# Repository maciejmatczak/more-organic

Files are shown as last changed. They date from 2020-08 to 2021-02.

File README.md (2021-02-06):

# More organic

Last time (five-by-six) Freecad was used to achieve the parametric design of plate and rest of case parts.

Now, the whole design is more complicated. When keys were purely orthogonal, Freecad handled that easily with multi transform, but column stagger + thumb cluster is a bit more challenging.

OpenSCAD with SolidPython was choosen to support CAD design.

There is a couple of interdigitated parts in this project. Initially, the idea was to define everything in `make` dependencies, but that didn't work out. For example: case depends on switches placement (which are placed with script), but also manually placed elements on a PCB itself (uC, jack, etc). But PCB depends on a case itself, as PCB edge definition comes from it...

Whole workflow ended up as a subset of action from `Makefile`, saved intermediate design files within the repo itself (.scad, .dxf, .json data dumps).

This board might be really similar to quite a few already existing great boards out there. An additional knob would be also nice.

# Parts of this project

## Design

The design of shared data, like:

- keys and diode positions
- mounting holes (pcb to plate, plate standoffs)

... is generated from `design/design.py` file. A bit of a math, logic and magic numbers (hand measurments, etc).

## Case

With use of SolidPython and dump of the footrpints from PCB, the whole assembly of plate, cover and pcb design is generated:

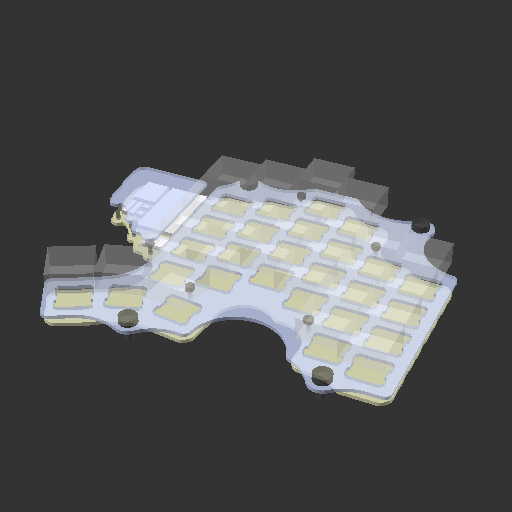
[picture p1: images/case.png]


Additionally, a collisions are shown in red (need of a manual validation):

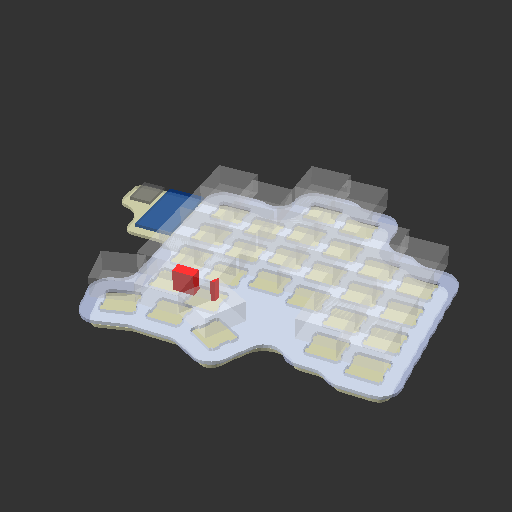
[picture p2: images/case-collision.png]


The whole idea for this design is to be kind of _organic_. Edges are naturally created form particular elements being _melted_ with each other. I am proud of that one.

Some footprints from KiCAD were "redesigned" in OpenSCAD as well (basic shapes).

Different coordinate system between this 2 worlds (KiCAD and OpenSCAD) is not fun. Also, KiCAD and it's weird `(0, 0)` placement.

Also, this board doesn't have a bottom plate.

From python scripts .scad files are baked, then .dxf and images. .dxf are used as a PCBs edge lines (for main PCB, cover and plate).

## PCB

Ordinary PCB design. Needs manual routing followup after every `make pcb-place` is invoked, manual PCB edge reload from case's .dxf.

There is a small chaos in submodules and parts actually being used. The really used one, should be:

- [Keebio-Parts.pretty](github.com:keebio/Keebio-Parts.pretty)
- [keebio-components](github.com:keebio/keebio-components)
- [keyswitches.pretty](github.com/maciejmatczak/keyswitches.pretty), forked from [daprice's](github.com/daprice/keyswitches.pretty); I additionally modify one footprint to be reversible

# Afterthoughts

Scripting backup is great. But a really well thought and defined data flow needs be designed first to keep everything well working with each other in a more complicated design like this.

Clean stages of project are a key, I believe. Imagine if your work had to be done by different engineers. Mechanical design, electrical design. Which parts of a project are a common data that needs to be agreed and locked? And how to validate if you didn't mess up with some updates?

In a middle of a design, there would be a need to change something - for sure! The changes in the _root_ should naturally produce a dependant actions to follow up (that's should be clearly visible). Steps should be clear.

Status quo is not exactly how I was imaging it, but with recent RSI issues being more severe, this project took longer than I thought. And one failed fabrication ;).

Highlights:

- KiCAD design scripting
  - data dumpers from a KiCAD PCB
  - footprint placers from such dump - with filtering included
- OpenSCAD and SolidPython
  - idea for a companion libraries (to KiCAD's)
- General project validation - pytest suite
  - checking characteristic elements in designs (number of holes)
  - proper file age (drc report should be **younger** than a design itself)

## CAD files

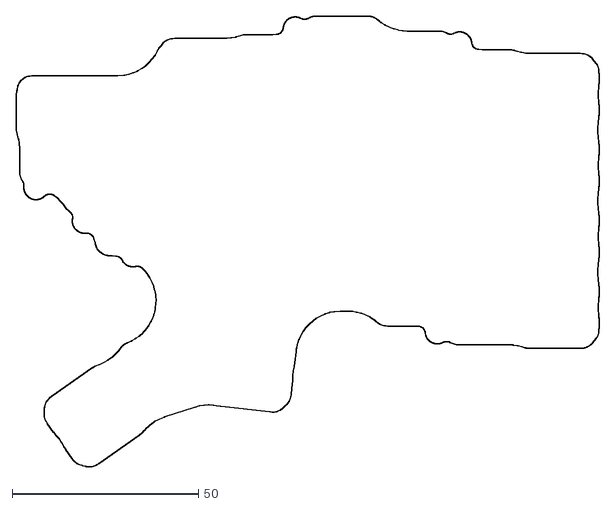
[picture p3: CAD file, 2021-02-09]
data/case/pcb.dxf
156.4 x 120.9

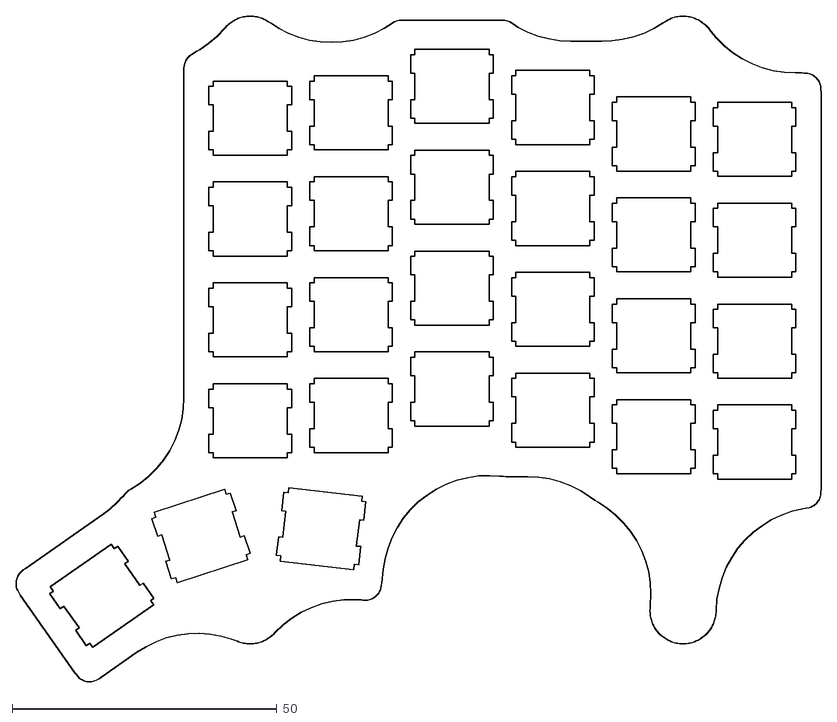
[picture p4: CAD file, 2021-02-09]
data/case/plate.dxf
152.0 x 125.7

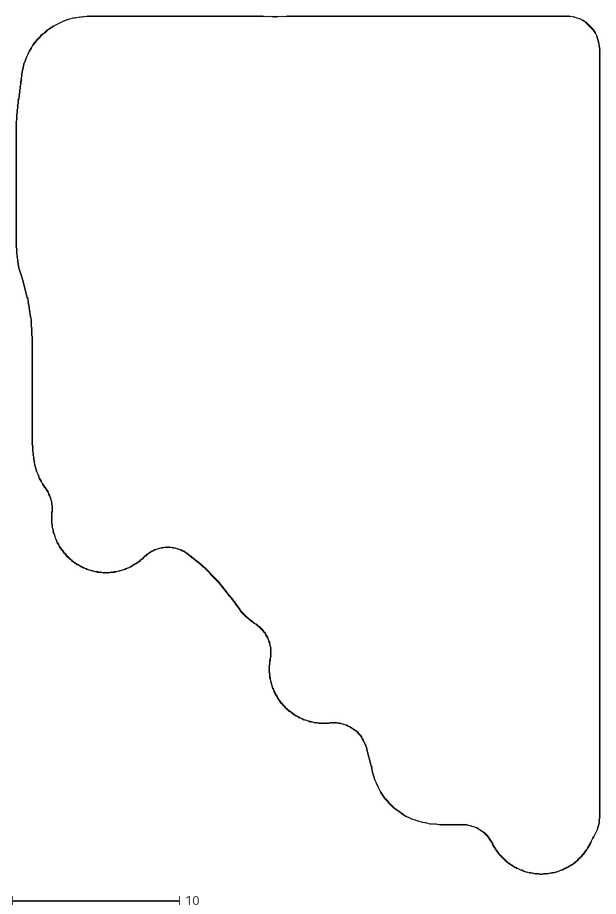
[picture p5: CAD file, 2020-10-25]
data/case/cover.dxf
34.8 x 51.2

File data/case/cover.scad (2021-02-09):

$fa = 6;
$fs = .1;


projection(cut = true) {
	color(c = [0.8000000000, 0.8500000000, 1, 0.5000000000]) {
		linear_extrude(height = 1.6000000000) {
			offset(r = 2) {
				offset(r = -2) {
					difference() {
						offset(r = -2) {
							offset(r = 2) {
								union() {
									offset(r = -12) {
										offset(r = 16) {
											intersection() {
												offset(r = -10) {
													offset(r = 10) {
														translate(v = [-16.2000000000, -42.8000000000]) {
															rotate(a = 180.0000000000) {
																polygon(paths = [[0, 1, 2, 3]], points = [[-1.5000000000, 1.5000000000], [8, 1.5000000000], [8, -6], [-1.5000000000, -6]]);
															}
														}
														translate(v = [-40.0000000000, -2.0000000000]) {
															color(c = [0.3000000000, 0.3000000000, 0.3000000000]) {
																mirror(v = [0, 1, 0]) {
																	polygon(paths = [[0, 1, 2, 3, 4, 5, 6, 7]], points = [[-5.3500000000, 12.1000000000], [5.3500000000, 12.1000000000], [5.3500000000, 0], [5.1000000000, 0], [5.1000000000, -2], [-5.1000000000, -2], [-5.1000000000, 0], [-5.3500000000, 0]]);
																}
															}
														}
														translate(v = [-24.0000000000, -17.8000000000]) {
															rotate(a = -90.0000000000) {
																color(c = [0.0040000000, 0.2274509804, 0.5764705882, 0.5000000000]) {
																	polygon(paths = [[0, 1, 2, 3]], points = [[-17.8000000000, 8.9000000000], [15.2000000000, 8.9000000000], [15.2000000000, -8.9000000000], [-17.8000000000, -8.9000000000]]);
																}
															}
														}
														translate(v = [-39.8000000000, -21.2000000000]) {
															rotate(a = -90.0000000000) {
																polygon(paths = [[0, 1, 2, 3]], points = [[-4.7000000000, -1.1000000000], [4.7000000000, -1.1000000000], [4.7000000000, 1.1000000000], [-4.7000000000, 1.1000000000]]);
															}
														}
														translate(v = [-43.3000000000, -21.2000000000]) {
															rotate(a = -90.0000000000) {
																polygon(paths = [[0, 1, 2, 3]], points = [[-4.7000000000, -1.1000000000], [4.7000000000, -1.1000000000], [4.7000000000, 1.1000000000], [-4.7000000000, 1.1000000000]]);
															}
														}
														translate(v = [-36.1000000000, -18.6000000000]) {
															rotate(a = 180.0000000000) {
																polygon(paths = [[0, 1, 2, 3]], points = [[-1.6500000000, -1.2400000000], [1.6500000000, -1.2400000000], [1.6500000000, 1.2400000000], [-1.6500000000, 1.2400000000]]);
															}
														}
														translate(v = [-36.1000000000, -24.4000000000]) {
															polygon(paths = [[0, 1, 2, 3]], points = [[-1.6500000000, -1.2400000000], [1.6500000000, -1.2400000000], [1.6500000000, 1.2400000000], [-1.6500000000, 1.2400000000]]);
														}
													}
												}
												translate(v = [0, -4]) {
													offset(r = -10) {
														offset(r = 10) {
															translate(v = [-16.2000000000, -42.8000000000]) {
																rotate(a = 180.0000000000) {
																	polygon(paths = [[0, 1, 2, 3]], points = [[-1.5000000000, 1.5000000000], [8, 1.5000000000], [8, -6], [-1.5000000000, -6]]);
																}
															}
															translate(v = [-40.0000000000, -2.0000000000]) {
																color(c = [0.3000000000, 0.3000000000, 0.3000000000]) {
																	mirror(v = [0, 1, 0]) {
																		polygon(paths = [[0, 1, 2, 3, 4, 5, 6, 7]], points = [[-5.3500000000, 12.1000000000], [5.3500000000, 12.1000000000], [5.3500000000, 0], [5.1000000000, 0], [5.1000000000, -2], [-5.1000000000, -2], [-5.1000000000, 0], [-5.3500000000, 0]]);
																	}
																}
															}
															translate(v = [-24.0000000000, -17.8000000000]) {
																rotate(a = -90.0000000000) {
																	color(c = [0.0040000000, 0.2274509804, 0.5764705882, 0.5000000000]) {
																		polygon(paths = [[0, 1, 2, 3]], points = [[-17.8000000000, 8.9000000000], [15.2000000000, 8.9000000000], [15.2000000000, -8.9000000000], [-17.8000000000, -8.9000000000]]);
																	}
																}
															}
															translate(v = [-39.8000000000, -21.2000000000]) {
																rotate(a = -90.0000000000) {
																	polygon(paths = [[0, 1, 2, 3]], points = [[-4.7000000000, -1.1000000000], [4.7000000000, -1.1000000000], [4.7000000000, 1.1000000000], [-4.7000000000, 1.1000000000]]);
																}
															}
															translate(v = [-43.3000000000, -21.2000000000]) {
																rotate(a = -90.0000000000) {
																	polygon(paths = [[0, 1, 2, 3]], points = [[-4.7000000000, -1.1000000000], [4.7000000000, -1.1000000000], [4.7000000000, 1.1000000000], [-4.7000000000, 1.1000000000]]);
																}
															}
															translate(v = [-36.1000000000, -18.6000000000]) {
																rotate(a = 180.0000000000) {
																	polygon(paths = [[0, 1, 2, 3]], points = [[-1.6500000000, -1.2400000000], [1.6500000000, -1.2400000000], [1.6500000000, 1.2400000000], [-1.6500000000, 1.2400000000]]);
																}
															}
															translate(v = [-36.1000000000, -24.4000000000]) {
																polygon(paths = [[0, 1, 2, 3]], points = [[-1.6500000000, -1.2400000000], [1.6500000000, -1.2400000000], [1.6500000000, 1.2400000000], [-1.6500000000, 1.2400000000]]);
															}
														}
													}
												}
											}
										}
									}
									offset(r = 2) {
										union() {
											translate(v = [63.6750000000, -68.6750000000]) {
												circle(r = 1.2500000000);
											}
											translate(v = [69.6750000000, 8.5250000000]) {
												circle(r = 1.2500000000);
											}
											translate(v = [25.5750000000, 12.5250000000]) {
												circle(r = 1.2500000000);
											}
											translate(v = [-31.0000000000, -39.0000000000]) {
												circle(r = 1.2500000000);
											}
											translate(v = [-18.0000000000, -48.0000000000]) {
												circle(r = 1.2500000000);
											}
											translate(v = [-44.0000000000, -30.0000000000]) {
												circle(r = 1.2500000000);
											}
										}
									}
								}
							}
						}
						translate(v = [-2, 0, 0]) {
							difference() {
								offset(r = -20) {
									offset(r = 20) {
										union() {
											offset(r = -13) {
												offset(r = 16) {
													translate(v = [13.4000000000, -78.5000000000]) {
														rotate(a = -6.6000000000) {
															square(center = true, size = [19.0500000000, 19.0500000000]);
														}
													}
													translate(v = [-9.3000000000, -79.9000000000]) {
														rotate(a = 18.0000000000) {
															square(center = true, size = [19.0500000000, 19.0500000000]);
														}
													}
													translate(v = [-28.0000000000, -91.2000000000]) {
														rotate(a = 35.0000000000) {
															square(center = true, size = [19.0500000000, 19.0500000000]);
														}
													}
													translate(v = [95.2500000000, -62.1500000000]) {
														square(center = true, size = [19.0500000000, 19.0500000000]);
													}
													translate(v = [76.2000000000, -61.1500000000]) {
														square(center = true, size = [19.0500000000, 19.0500000000]);
													}
													translate(v = [57.1500000000, -56.1500000000]) {
														square(center = true, size = [19.0500000000, 19.0500000000]);
													}
													translate(v = [38.1000000000, -52.1500000000]) {
														square(center = true, size = [19.0500000000, 19.0500000000]);
													}
													translate(v = [19.0500000000, -57.1500000000]) {
														square(center = true, size = [19.0500000000, 19.0500000000]);
													}
													translate(v = [0.0000000000, -58.1500000000]) {
														square(center = true, size = [19.0500000000, 19.0500000000]);
													}
													translate(v = [95.2500000000, -43.1000000000]) {
														square(center = true, size = [19.0500000000, 19.0500000000]);
													}
													translate(v = [76.2000000000, -42.1000000000]) {
														square(center = true, size = [19.0500000000, 19.0500000000]);
													}
													translate(v = [57.1500000000, -37.1000000000]) {
														square(center = true, size = [19.0500000000, 19.0500000000]);
													}
													translate(v = [38.1000000000, -33.1000000000]) {
														square(center = true, size = [19.0500000000, 19.0500000000]);
													}
													translate(v = [19.0500000000, -38.1000000000]) {
														square(center = true, size = [19.0500000000, 19.0500000000]);
													}
													translate(v = [0.0000000000, -39.1000000000]) {
														square(center = true, size = [19.0500000000, 19.0500000000]);
													}
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

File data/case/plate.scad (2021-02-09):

$fa = 6;
$fs = .1;


projection(cut = true) {
	color(c = [0.8000000000, 0.8500000000, 1, 0.5000000000]) {
		linear_extrude(height = 1.6000000000) {
			difference() {
				offset(r = -20) {
					offset(r = 20) {
						union() {
							offset(r = -13) {
								offset(r = 16) {
									translate(v = [13.4000000000, -78.5000000000]) {
										rotate(a = -6.6000000000) {
											square(center = true, size = [19.0500000000, 19.0500000000]);
										}
									}
									translate(v = [-9.3000000000, -79.9000000000]) {
										rotate(a = 18.0000000000) {
											square(center = true, size = [19.0500000000, 19.0500000000]);
										}
									}
									translate(v = [-28.0000000000, -91.2000000000]) {
										rotate(a = 35.0000000000) {
											square(center = true, size = [19.0500000000, 19.0500000000]);
										}
									}
									translate(v = [95.2500000000, -62.1500000000]) {
										square(center = true, size = [19.0500000000, 19.0500000000]);
									}
									translate(v = [76.2000000000, -61.1500000000]) {
										square(center = true, size = [19.0500000000, 19.0500000000]);
									}
									translate(v = [57.1500000000, -56.1500000000]) {
										square(center = true, size = [19.0500000000, 19.0500000000]);
									}
									translate(v = [38.1000000000, -52.1500000000]) {
										square(center = true, size = [19.0500000000, 19.0500000000]);
									}
									translate(v = [19.0500000000, -57.1500000000]) {
										square(center = true, size = [19.0500000000, 19.0500000000]);
									}
									translate(v = [0.0000000000, -58.1500000000]) {
										square(center = true, size = [19.0500000000, 19.0500000000]);
									}
									translate(v = [95.2500000000, -43.1000000000]) {
										square(center = true, size = [19.0500000000, 19.0500000000]);
									}
									translate(v = [76.2000000000, -42.1000000000]) {
										square(center = true, size = [19.0500000000, 19.0500000000]);
									}
									translate(v = [57.1500000000, -37.1000000000]) {
										square(center = true, size = [19.0500000000, 19.0500000000]);
									}
									translate(v = [38.1000000000, -33.1000000000]) {
										square(center = true, size = [19.0500000000, 19.0500000000]);
									}
									translate(v = [19.0500000000, -38.1000000000]) {
										square(center = true, size = [19.0500000000, 19.0500000000]);
									}
									translate(v = [0.0000000000, -39.1000000000]) {
										square(center = true, size = [19.0500000000, 19.0500000000]);
									}
									translate(v = [95.2500000000, -24.0500000000]) {
										square(center = true, size = [19.0500000000, 19.0500000000]);
									}
									translate(v = [76.2000000000, -23.0500000000]) {
										square(center = true, size = [19.0500000000, 19.0500000000]);
									}
									translate(v = [57.1500000000, -18.0500000000]) {
										square(center = true, size = [19.0500000000, 19.0500000000]);
									}
									translate(v = [38.1000000000, -14.0500000000]) {
										square(center = true, size = [19.0500000000, 19.0500000000]);
									}
									translate(v = [19.0500000000, -19.0500000000]) {
										square(center = true, size = [19.0500000000, 19.0500000000]);
									}
									translate(v = [0.0000000000, -20.0500000000]) {
										square(center = true, size = [19.0500000000, 19.0500000000]);
									}
									translate(v = [95.2500000000, -5.0000000000]) {
										square(center = true, size = [19.0500000000, 19.0500000000]);
									}
									translate(v = [76.2000000000, -4.0000000000]) {
										square(center = true, size = [19.0500000000, 19.0500000000]);
									}
									translate(v = [57.1500000000, 1.0000000000]) {
										square(center = true, size = [19.0500000000, 19.0500000000]);
									}
									translate(v = [38.1000000000, 5.0000000000]) {
										square(center = true, size = [19.0500000000, 19.0500000000]);
									}
									translate(v = [19.0500000000, -0.0000000000]) {
										square(center = true, size = [19.0500000000, 19.0500000000]);
									}
									translate(v = [0.0000000000, -1.0000000000]) {
										square(center = true, size = [19.0500000000, 19.0500000000]);
									}
								}
							}
							offset(r = 4) {
								union() {
									translate(v = [0, 12]) {
										circle(r = 2.2500000000);
									}
									translate(v = [0, -94]) {
										circle(r = 2.2500000000);
									}
									translate(v = [81.7250000000, 12]) {
										circle(r = 2.2500000000);
									}
									translate(v = [81.7250000000, -94]) {
										circle(r = 2.2500000000);
									}
								}
							}
						}
					}
				}
				translate(v = [13.4000000000, -78.5000000000]) {
					rotate(a = -6.6000000000) {
						translate(v = [-7.8000000000, -7.0000000000]) {
							polygon(paths = [[0, 1, 2, 3, 4, 5, 6, 7, 8, 9, 10, 11, 12, 13, 14, 15, 16, 17, 18, 19]], points = [[0.8000000000, 0], [14.8000000000, 0], [14.8000000000, 1], [15.6000000000, 1], [15.6000000000, 4.5000000000], [14.8000000000, 4.5000000000], [14.8000000000, 9.5000000000], [15.6000000000, 9.5000000000], [15.6000000000, 13], [14.8000000000, 13], [14.8000000000, 14], [0.8000000000, 14], [0.8000000000, 13], [0, 13], [0, 9.5000000000], [0.8000000000, 9.5000000000], [0.8000000000, 4.5000000000], [0, 4.5000000000], [0, 1], [0.8000000000, 1]]);
						}
					}
				}
				translate(v = [-9.3000000000, -79.9000000000]) {
					rotate(a = 18.0000000000) {
						translate(v = [-7.8000000000, -7.0000000000]) {
							polygon(paths = [[0, 1, 2, 3, 4, 5, 6, 7, 8, 9, 10, 11, 12, 13, 14, 15, 16, 17, 18, 19]], points = [[0.8000000000, 0], [14.8000000000, 0], [14.8000000000, 1], [15.6000000000, 1], [15.6000000000, 4.5000000000], [14.8000000000, 4.5000000000], [14.8000000000, 9.5000000000], [15.6000000000, 9.5000000000], [15.6000000000, 13], [14.8000000000, 13], [14.8000000000, 14], [0.8000000000, 14], [0.8000000000, 13], [0, 13], [0, 9.5000000000], [0.8000000000, 9.5000000000], [0.8000000000, 4.5000000000], [0, 4.5000000000], [0, 1], [0.8000000000, 1]]);
						}
					}
				}
				translate(v = [-28.0000000000, -91.2000000000]) {
					rotate(a = 35.0000000000) {
						translate(v = [-7.8000000000, -7.0000000000]) {
							polygon(paths = [[0, 1, 2, 3, 4, 5, 6, 7, 8, 9, 10, 11, 12, 13, 14, 15, 16, 17, 18, 19]], points = [[0.8000000000, 0], [14.8000000000, 0], [14.8000000000, 1], [15.6000000000, 1], [15.6000000000, 4.5000000000], [14.8000000000, 4.5000000000], [14.8000000000, 9.5000000000], [15.6000000000, 9.5000000000], [15.6000000000, 13], [14.8000000000, 13], [14.8000000000, 14], [0.8000000000, 14], [0.8000000000, 13], [0, 13], [0, 9.5000000000], [0.8000000000, 9.5000000000], [0.8000000000, 4.5000000000], [0, 4.5000000000], [0, 1], [0.8000000000, 1]]);
						}
					}
				}
				translate(v = [95.2500000000, -62.1500000000]) {
					translate(v = [-7.8000000000, -7.0000000000]) {
						polygon(paths = [[0, 1, 2, 3, 4, 5, 6, 7, 8, 9, 10, 11, 12, 13, 14, 15, 16, 17, 18, 19]], points = [[0.8000000000, 0], [14.8000000000, 0], [14.8000000000, 1], [15.6000000000, 1], [15.6000000000, 4.5000000000], [14.8000000000, 4.5000000000], [14.8000000000, 9.5000000000], [15.6000000000, 9.5000000000], [15.6000000000, 13], [14.8000000000, 13], [14.8000000000, 14], [0.8000000000, 14], [0.8000000000, 13], [0, 13], [0, 9.5000000000], [0.8000000000, 9.5000000000], [0.8000000000, 4.5000000000], [0, 4.5000000000], [0, 1], [0.8000000000, 1]]);
					}
				}
				translate(v = [76.2000000000, -61.1500000000]) {
					translate(v = [-7.8000000000, -7.0000000000]) {
						polygon(paths = [[0, 1, 2, 3, 4, 5, 6, 7, 8, 9, 10, 11, 12, 13, 14, 15, 16, 17, 18, 19]], points = [[0.8000000000, 0], [14.8000000000, 0], [14.8000000000, 1], [15.6000000000, 1], [15.6000000000, 4.5000000000], [14.8000000000, 4.5000000000], [14.8000000000, 9.5000000000], [15.6000000000, 9.5000000000], [15.6000000000, 13], [14.8000000000, 13], [14.8000000000, 14], [0.8000000000, 14], [0.8000000000, 13], [0, 13], [0, 9.5000000000], [0.8000000000, 9.5000000000], [0.8000000000, 4.5000000000], [0, 4.5000000000], [0, 1], [0.8000000000, 1]]);
					}
				}
				translate(v = [57.1500000000, -56.1500000000]) {
					translate(v = [-7.8000000000, -7.0000000000]) {
						polygon(paths = [[0, 1, 2, 3, 4, 5, 6, 7, 8, 9, 10, 11, 12, 13, 14, 15, 16, 17, 18, 19]], points = [[0.8000000000, 0], [14.8000000000, 0], [14.8000000000, 1], [15.6000000000, 1], [15.6000000000, 4.5000000000], [14.8000000000, 4.5000000000], [14.8000000000, 9.5000000000], [15.6000000000, 9.5000000000], [15.6000000000, 13], [14.8000000000, 13], [14.8000000000, 14], [0.8000000000, 14], [0.8000000000, 13], [0, 13], [0, 9.5000000000], [0.8000000000, 9.5000000000], [0.8000000000, 4.5000000000], [0, 4.5000000000], [0, 1], [0.8000000000, 1]]);
					}
				}
				translate(v = [38.1000000000, -52.1500000000]) {
					translate(v = [-7.8000000000, -7.0000000000]) {
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

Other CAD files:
data/case/assembly.scad
data/case/pcb.scad

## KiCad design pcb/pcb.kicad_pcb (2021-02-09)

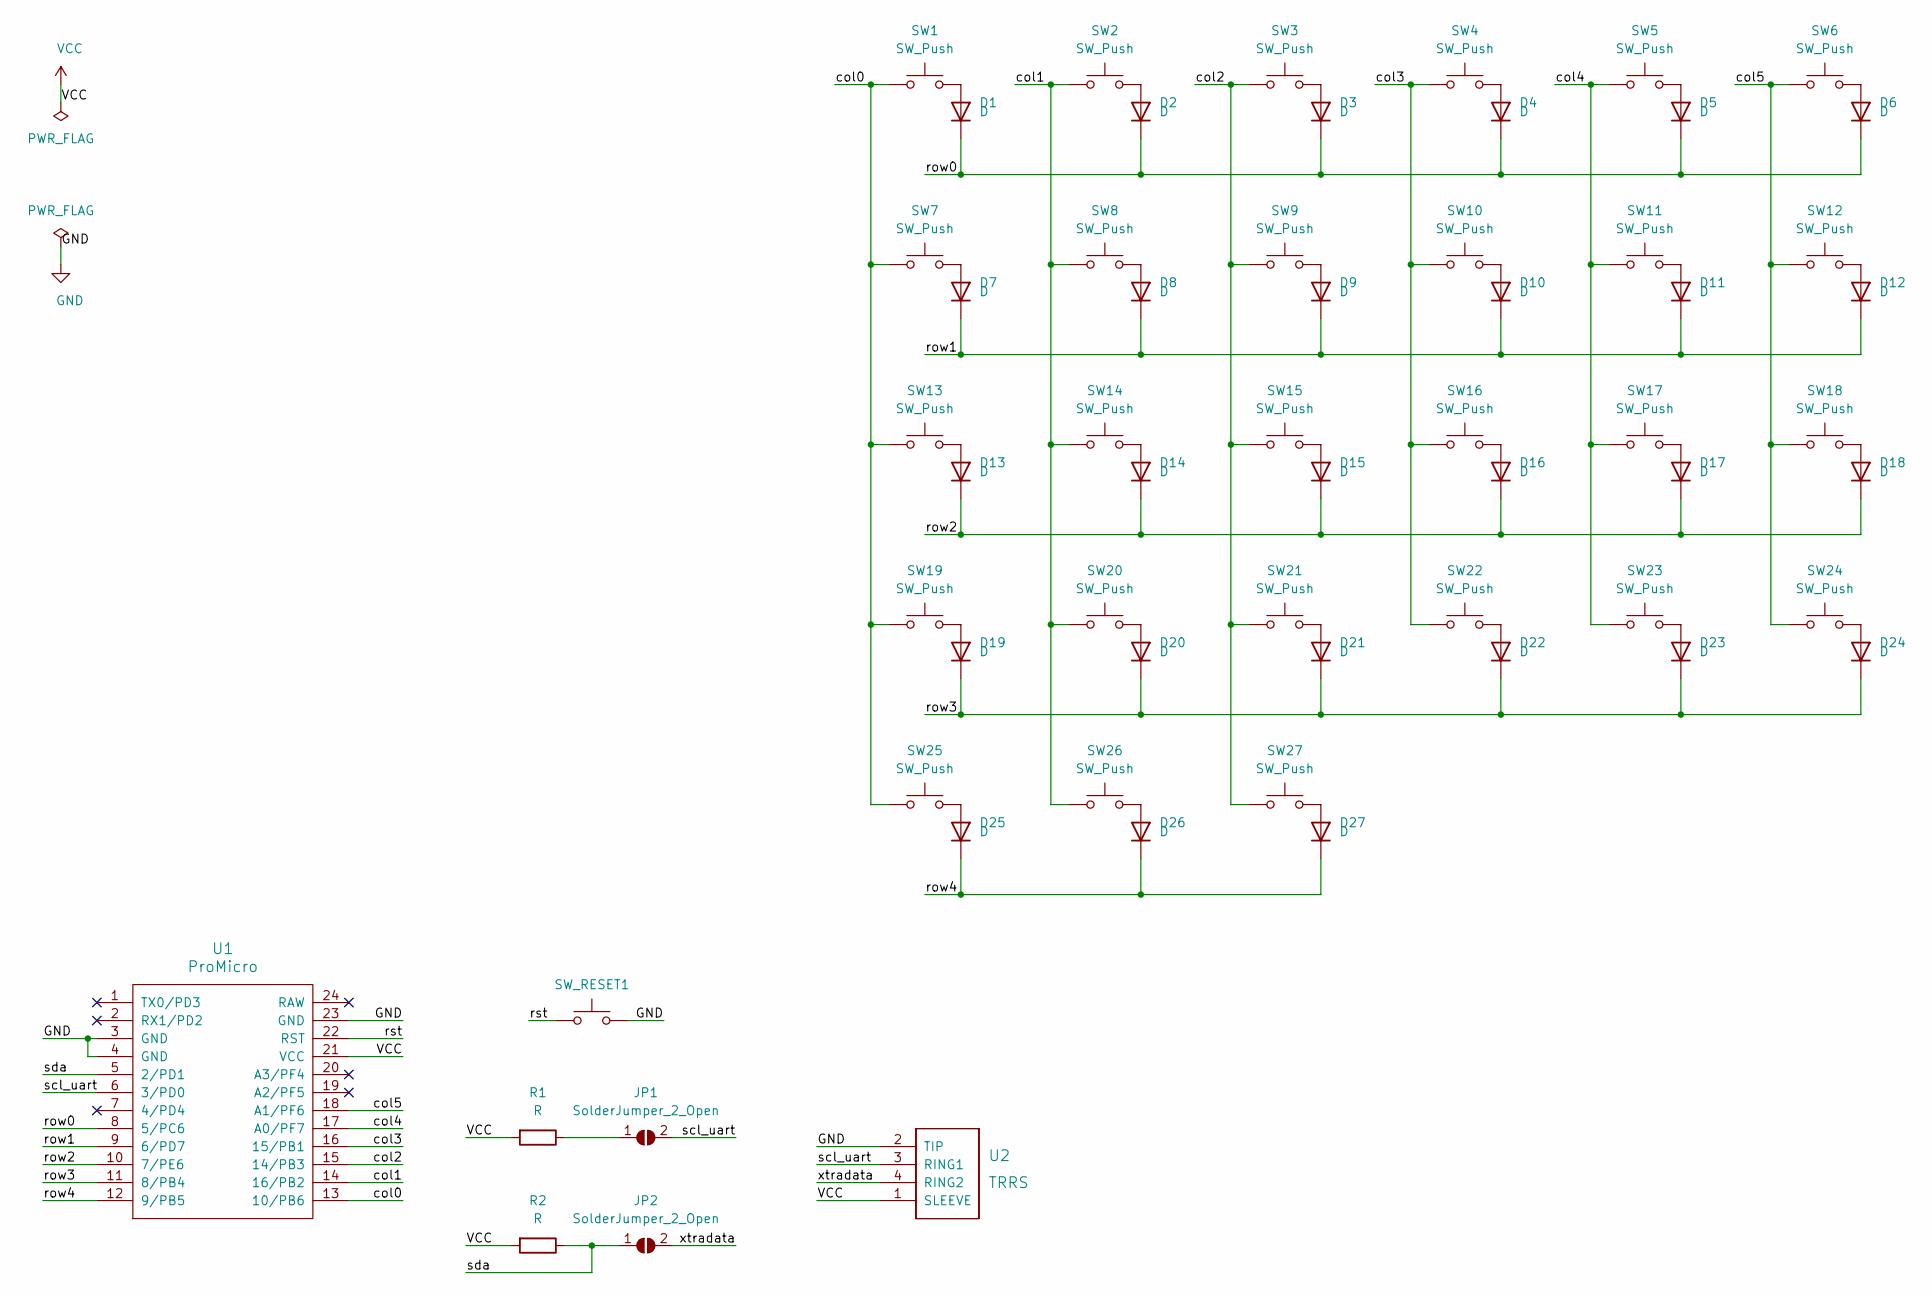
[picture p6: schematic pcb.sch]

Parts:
D1, D2, D3, D4, D5, D6, D7, D8, D9, D10, D11, D12, D13, D14, D15, D16, D17, D18, D19, D20, D21, D22, D23, D24, D25, D26, D27: D; Diode-dual
JP1, JP2: SolderJumper_2_Open; SolderJumper-2_P1.3mm_Open_RoundedPad1.0x1.5mm
R1, R2: R; Resistor-Hybrid
SW1, SW2, SW3, SW4, SW5, SW6, SW7, SW8, SW9, SW10, SW11, SW12, SW13, SW14, SW15, SW16, SW17, SW18, SW19, SW20, SW21, SW22, SW23, SW24, SW25, SW26, SW27: SW_Push; Kailh_socket_MX_optional_reversible_alt
SW_RESET1: MX; SW_PUSH_6mm_H7.3mm
U1: ProMicro; ArduinoProMicro
U2: TRRS; TRRS-PJ-320A-dual

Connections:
/col0: SW1.1, SW7.1, SW13.1, SW19.1, SW25.1, U1.13 (10/PB6)
/col1: SW2.1, SW8.1, SW14.1, SW20.1, SW26.1, U1.14 (16/PB2)
/col2: SW3.1, SW9.1, SW15.1, SW21.1, SW27.1, U1.15 (14/PB3)
/col3: SW4.1, SW10.1, SW16.1, SW22.1, U1.16 (15/PB1)
/col4: SW5.1, SW11.1, SW17.1, SW23.1, U1.17 (A0/PF7)
/col5: SW6.1, SW12.1, SW18.1, SW24.1, U1.18 (A1/PF6)
/row0: D1.1 (K), D2.1 (K), D3.1 (K), D4.1 (K), D5.1 (K), D6.1 (K), U1.8 (5/PC6)
/row1: D7.1 (K), D8.1 (K), D9.1 (K), D10.1 (K), D11.1 (K), D12.1 (K), U1.9 (6/PD7)
/row2: D13.1 (K), D14.1 (K), D15.1 (K), D16.1 (K), D17.1 (K), D18.1 (K), U1.10 (7/PE6)
/row3: D19.1 (K), D20.1 (K), D21.1 (K), D22.1 (K), D23.1 (K), D24.1 (K), U1.11 (8/PB4)
/row4: D25.1 (K), D26.1 (K), D27.1 (K), U1.12 (9/PB5)
/rst: SW_RESET1.1, U1.22 (RST)
/scl_uart: JP1.2 (B), U1.6 (3/PD0), U2.3 (RING1)
/sda: JP2.1 (A), R2.1, U1.5 (2/PD1)
/xtradata: JP2.2 (B), U2.4 (RING2)
GND: SW_RESET1.2, U1.3 (GND), U1.4 (GND), U1.23 (GND), U2.2 (TIP)
unnamed: D1.2 (A), SW1.2
unnamed: D2.2 (A), SW2.2
unnamed: D3.2 (A), SW3.2
unnamed: D4.2 (A), SW4.2
unnamed: D5.2 (A), SW5.2
unnamed: D6.2 (A), SW6.2
unnamed: D7.2 (A), SW7.2
unnamed: D8.2 (A), SW8.2
unnamed: D9.2 (A), SW9.2
unnamed: D10.2 (A), SW10.2
unnamed: D11.2 (A), SW11.2
unnamed: D12.2 (A), SW12.2
unnamed: D13.2 (A), SW13.2
unnamed: D14.2 (A), SW14.2
unnamed: D15.2 (A), SW15.2
unnamed: D16.2 (A), SW16.2
unnamed: D17.2 (A), SW17.2
unnamed: D18.2 (A), SW18.2
unnamed: D19.2 (A), SW19.2
unnamed: D20.2 (A), SW20.2
unnamed: D21.2 (A), SW21.2
unnamed: D22.2 (A), SW22.2
unnamed: D23.2 (A), SW23.2
unnamed: D24.2 (A), SW24.2
unnamed: D25.2 (A), SW25.2
unnamed: D26.2 (A), SW26.2
unnamed: D27.2 (A), SW27.2
unnamed: JP1.1 (A), R1.1
VCC: R1.2, R2.2, U1.21 (VCC), U2.1 (SLEEVE)

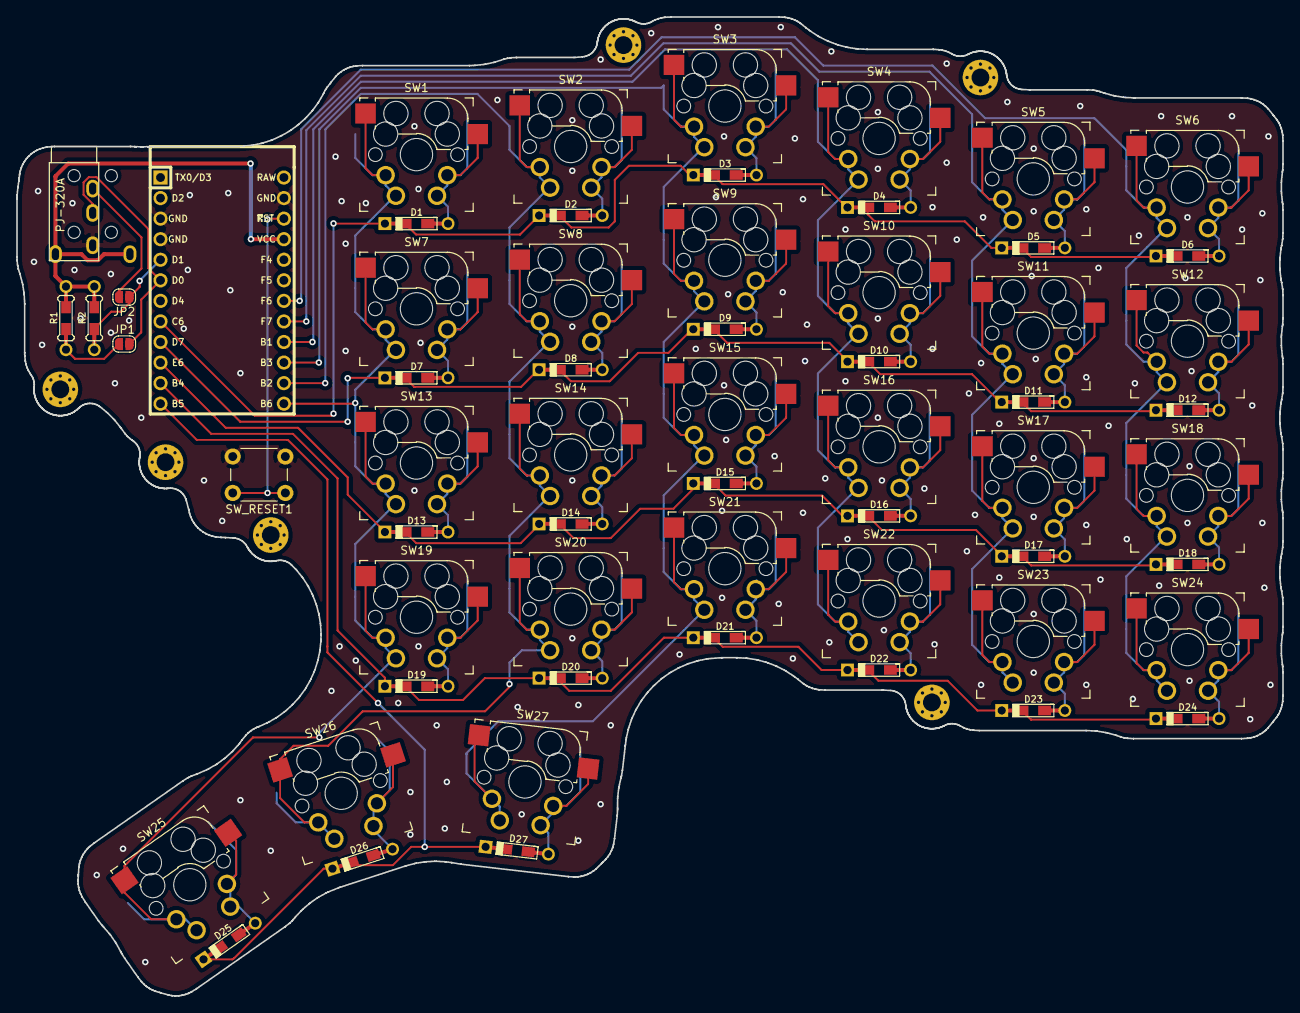
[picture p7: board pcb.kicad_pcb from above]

Board: 2 copper layers, 156.4 x 120.9 mm, 64 parts (0 on the bottom side), 45 nets.

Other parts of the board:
generated: MountingHole_2.2mm_M2_Pad_Via
generated#2, generated#3: MountingHole_2.2mm_M2_Pad_Via

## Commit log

2020-08-02 Add initial board, start working on PCB placer script
    [more-organic.kicad_pcb, more-organic.sch]
2020-08-02 Switch to fork's feature branch
2020-08-22 Rework on design process, case files
2020-08-22 Add readme, images
    [more-organic.kicad_pcb, more-organic.sch]
2020-09-03 Add screw holes
2020-09-03 Add screw and screw holes
2020-09-03 Hierarchicalize the parts of design
    Sub elements are totally seperated now, assembly is a different view as well.
2020-09-07 Add phony case target
2020-09-07 Add reserved space and 3d model of arduino
2020-09-07 Fix rotating math (KiCAD y axis...)
2020-09-07 Update pcb with recent placement, remove 3 not used switches
    [more-organic.kicad_pcb, more-organic.sch]
2020-09-07 Move, update pcb scripts
2020-09-07 Add pcb targets (placer)
2020-09-13 Redesigning makefile, design and pcb data flow
    [more-organic.kicad_pcb]
2020-09-13 Add dumper for PCB data
    [more-organic.kicad_pcb]
2020-09-13 Follow up with new data flow on case
    [more-organic.kicad_pcb]
2020-09-19 Rename small case to cover
2020-09-19 Add non existing option for footprint dump
2020-09-19 Routed current pcb
    [more-organic.kicad_pcb]
2020-09-19 Add cover and plate makefile placer commands
    [more-organic.kicad_pcb, plate.kicad_pcb]
2020-09-19 Add simple filtering args
2020-09-19 Move main pcb files
    [pcb.kicad_pcb, pcb.sch]
2020-09-19 Add cove design
    [cover.kicad_pcb]
2020-10-25 Move case output files to data/case
    [assembly.scad, cover.dxf, cover.scad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]
2020-10-25 Move footprint dump to data/pcb
    [assembly.scad, cover.scad, pcb.scad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]
2020-10-25 Redesign thumb cluster
    [assembly.scad, cover.scad, pcb.dxf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]
2020-10-25 Add missing mh from pcb to plate
2020-10-25 Swtich plate place command to use pcb dump
2020-10-31 Adjust key placement
    [assembly.scad, cover.scad, pcb.kicad_pcb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]
2020-10-31 Regenerate dxfs
    [pcb.dxf, pcb.kicad_pcb, plate.dxf]
2020-10-31 Update pcb
    [pcb.kicad_pcb]
2020-10-31 Fix plate-place
2020-10-31 Replace the mounting holes
    [cover.kicad_pcb, plate.kicad_pcb]
2020-10-31 Add tests for pcb validation
2020-11-01 Small tweaks, regenerate PCB
    [pcb.kicad_pcb]
2020-11-01 Update case image
2021-02-06 Remove unused M2 pcb to cover from design.py
2021-02-09 Change the column offsets post 1 fab
    After 1 fab keyboard seemed to be too aggressive. Boo hoo.
    Lessons learned. New measurments. And halfing it either way.
    [assembly.scad, cover.scad, pcb.dxf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]
2021-02-09 Modify test to expect 6 holes in PCB
2021-02-09 Newest pcb report
2021-02-09 Route new switch placement
    [pcb.kicad_pcb]
2021-02-13 Regenerate plate
    [plate.kicad_pcb]
2021-02-13 Modify test: plate to have 7 mounting holes
